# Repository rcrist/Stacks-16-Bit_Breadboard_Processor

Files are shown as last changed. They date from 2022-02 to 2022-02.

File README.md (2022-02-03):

# Stacks-16-Bit_Breadboard_Processor

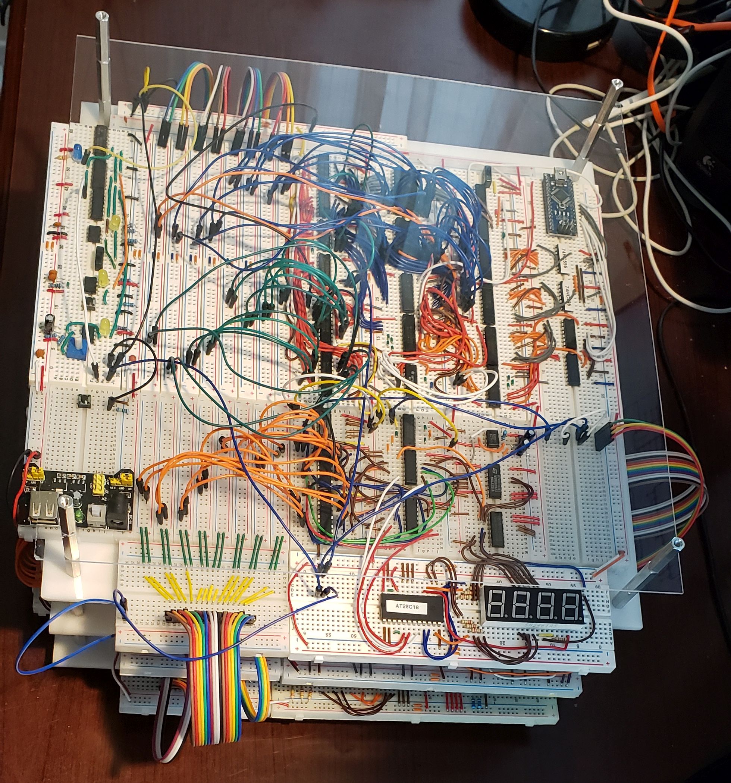
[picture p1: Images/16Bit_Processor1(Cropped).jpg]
Processor Image

Files associated with the Stacks 16-Bit Breadboard Processor project.
A full description of the project can be found on instructables at https://www.instructables.com/Stacks-A16-Bit-Breadboard-Processor/.

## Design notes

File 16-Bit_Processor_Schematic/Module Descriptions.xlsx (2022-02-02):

Layer | Module | Addr | Input | Output | Description
Top Layer | Power Supply |  | 6-12VDC | 5VDC | Computer main power supply
 | Clock |  | none | Clock | Computer main clock
 | Program Counter |  | Clock | Prog count | Computer main program counter
 | Program Memory
 | PROG | PC USB Arduino | PC USB Arduino | Prog Mem | In PROG mode, load program memory RAM with user program
 | RUN-memwr | ImmRegister | Data Bus
 | RUN-memrd | ImmRegister |  | Data Bus
 | Output Display |  | Data Bus | 7-Seg Display | Display data bus in hex
 | Branch |  | Flags | Jmp Cmd | Checks for branch cmd, if cmd, sends jmp cmd to PC
 | Branch Register |  | Inst Bus | PC | Branch register stores branch/jmp address, sends to PC load inputs
 | Decoder |  | Inst Bus | Cmd bus | Computer controller
Middle Layer | rs0 |  | Data Bus | ALU-A | Register to store ALU-A input for single cycle commands
 | rs1 |  | Data Bus | ALU-B | Register to store ALU-B input for single cycle commands
 | rd |  | ALU-Y | Data Bus | Register to store the ALU-Y result for single cycle commands
 | ALU - Math Unit |  | A & B | Y | Performs ALU addition, subtraction, AND, OR, XOR
 | ALU - Shift Unit |  | A | Y | Performs shift left, shift right, rotate left, rotate right
 | ALU - Comparator |  | A | Zero | Sets Zero output to 1 if A=0
 | Flags Register |  | Flags | Flags | 8-bit storage register for flags
Bottom Layer | rs2 |  | Data Bus | Data Bus | General purpose register for temporary 16-bit data storage
 | rs3 |  | Data Bus | Data Bus | General purpose register for temporary 16-bit data storage
 | Imm Register |  | Inst Bus | Data Bus | Storage for 16-bit data during Imm commands
 | RAM |  | Data Bus | Data Bus | HM6116 (2Kx16) RAM
 | EEPROM Programmer |  | PC USB | EEPROM | EEPROM programmer on separate power supply.

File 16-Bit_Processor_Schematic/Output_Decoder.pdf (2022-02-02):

1010 A
1011 B
1100 C
1101 D
1110 E

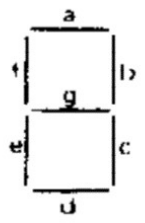
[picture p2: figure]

Assume a is lsb, g is msb | 1111 | F
Bank 3 | Bank 2 | Bank 1 | Bank 0 | I/O6 | I/O5 | I/O4 | I/O3 | I/O2 | I/O1 | I/O0
a4-a5 | a4-a5 | a4-a5 | a4-a5 | a0-a3 | g | f | e | d | c | b | a | ROM Code | Bank 0 Addr Bank 1 Addr Bank 2 Addr Bank 3 Addr
11 | 10 | 01 | 00 | 0 | 0 | 1 | 1 | 1 | 1 | 1 | 1 | 0x3F | 0x00 | 0x10 | 0x20 | 0x30
11 | 10 | 01 | 00 | 1 | 0 | 0 | 0 | 0 | 1 | 1 | 0 | 0x06 | 0x01 | 0x11 | 0x21 | 0x31
11 | 10 | 01 | 00 | 2 | 1 | 0 | 1 | 1 | 0 | 1 | 1 | 0x5B | 0x02 | 0x12 | 0x22 | 0x32
11 | 10 | 01 | 00 | 3 | 1 | 0 | 0 | 1 | 1 | 1 | 1 | 0x4F | 0x03 | 0x13 | 0x23 | 0x33
11 | 10 | 01 | 00 | 4 | 1 | 1 | 0 | 0 | 1 | 1 | 0 | 0x66 | 0x04 | 0x14 | 0x24 | 0x34
11 | 10 | 01 | 00 | 5 | 1 | 1 | 0 | 1 | 1 | 0 | 1 | 0x6D | 0x05 | 0x15 | 0x25 | 0x35
11 | 10 | 01 | 00 | 6 | 1 | 1 | 1 | 1 | 1 | 0 | 1 | 0x7D | 0x06 | 0x16 | 0x26 | 0x36
11 | 10 | 01 | 00 | 7 | 0 | 0 | 0 | 0 | 1 | 1 | 1 | 0x07 | 0x07 | 0x17 | 0x27 | 0x37
11 | 10 | 01 | 00 | 8 | 1 | 1 | 1 | 1 | 1 | 1 | 1 | 0x7F | 0x08 | 0x18 | 0x28 | 0x38
11 | 10 | 01 | 00 | 9 | 1 | 1 | 0 | 1 | 1 | 1 | 1 | 0x6F | 0x09 | 0x19 | 0x29 | 0x39
11 | 10 | 01 | 00 | a | 1 | 1 | 1 | 0 | 1 | 1 | 1 | 0x77 | 0x0A | 0x1A | 0x2A | 0x3A

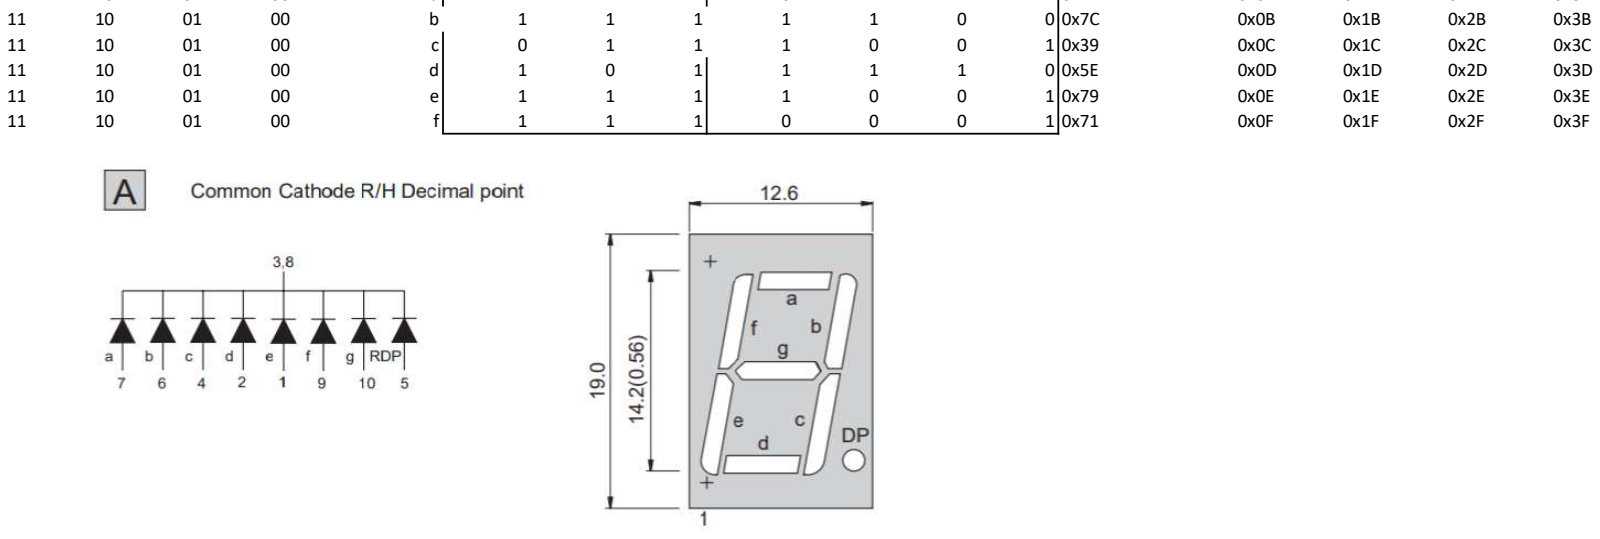
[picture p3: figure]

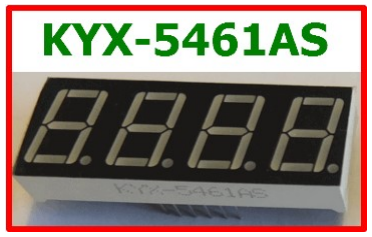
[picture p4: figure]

KYX-5461AS 4x7-Segment Display //display pins
int segA = 5; // >> 11
int segB = 13; // >> 7
int segC = 10; // >> 4

int d1 = 6; // >> 12
int d2 = 3; // >> 9
int d3 = 2; // >> 8
int d4 = 12; // >> 6

int segD = 8; // >> 2
int segE = 7; // >> 1
int segF = 4; // >> 10
int segG = 11; // >> 5
int segPt = 9; // >> 3
//display digit

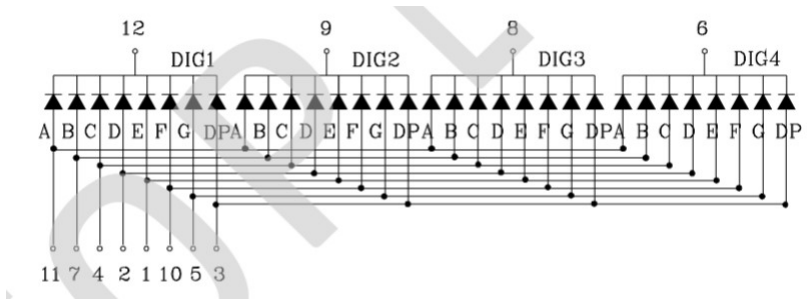
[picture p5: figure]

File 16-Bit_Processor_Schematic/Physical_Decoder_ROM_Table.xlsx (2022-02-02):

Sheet: v6
 |  |  |  | Rsrc |  |  | Rdest |  |  |  |  | ROM2 |  |  |  |  |  |  |  | ROM1 |  |  |  |  |  |  |  | ROM0 |  |  |  |  |  |  |  | ROM2 | ROM1 | ROM0
 |  |  |  | rdOE | rs2OE | rs3OE | rs3WE | rs2WE | rdWE | rs1WE | rs0WE | reserved | reserved | reserved | brWE | br2 | br1 | br0 | sf | reserved | reserved | immOE | memWE | memOE | outEN | imem | imm | aluOP5 | aluOP4 | aluOP3 | aluOP2 | aluOP1 | aluOP0 | hlt | no-op
 |  |  |  | 31 | 30 | 29 | 28 | 27 | 26 | 25 | 24 | 23 | 22 | 21 | 20 | 19 | 18 | 17 | 16 | 15 | 14 | 13 | 12 | 11 | 10 | 9 | 8 | 7 | 6 | 5 | 4 | 3 | 2 | 1 | 0
dec addr | assy mne | # Cycles | description |  |  |  |  |  |  |  |  |  |  |  |  |  |  |  |  |  |  |  |  |  |  |  |  |  |  |  |  |  |  |  |  |  |  |  | dec addr | hex addr
00 | nop | 1 | nop | 0 | 0 | 0 | 0 | 0 | 0 | 0 | 0 | 0 | 0 | 0 | 0 | 0 | 0 | 0 | 0 | 0 | 0 | 0 | 0 | 0 | 0 | 0 | 0 | 0 | 0 | 0 | 0 | 0 | 0 | 0 | 0 | 0x00 | 0x00 | 0x00 | 00 | 00
01 | hlt | 1 | hlt stop clock | 0 | 0 | 0 | 0 | 0 | 0 | 0 | 0 | 0 | 0 | 0 | 0 | 0 | 0 | 0 | 0 | 0 | 0 | 0 | 0 | 0 | 0 | 0 | 0 | 0 | 0 | 0 | 0 | 0 | 0 | 1 | 0 | 0x00 | 0x00 | 0x02 | 01 | 01
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

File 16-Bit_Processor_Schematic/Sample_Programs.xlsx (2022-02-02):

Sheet: Movi
Sample Program: Load rs0 with imm value
Load immReg with imm number |  |  | 2021-12-28 | 0x1C
Load rs0 with immReg value
Dest | rs0 | 000
 | rs1 | 001
 | rd | 010
 | immReg | 011
Source | rs0 | 000
 | rs1 | 001
 | imm | 010
 | mem | 011
 |  |  |  |  |  | Reg Signals |  |  | Decoder Signals
PM Addr | Assy | Desc | Inst (Dest) | Source | Op Code | rs0WE | rs1WE | imm | srcOE | outEN | edOE | m5 | m4 | m3 | m2 | m1 | m0 | Operation
0x0000 | movi rs0, imm | rs0 = imm | 011 | 010 | 0000 0100 | 1 |  | 1 |  |  |  |  |  |  |  |  |  | If movi, set imm=1 and rsoWE=1, next clk writes imm data to imReg
0x0001 |  |  | 000 | 000 | 0001 1100 |  |  |  |  |  |  |  |  |  |  |  |  | If imm=1, force a nop in decoder
Binary to Hex
1010 | A
1011 | B
1100 | C
1101 | D
1110 | E
1111 | F

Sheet: Add
Sample Program: Add Two Numbers
Load RS0 with 1st number |  |  | 2021-12-28 | 0x1C
Load RS1 with 2nd number |  |  | 2021-12-14 | 0x0E
Add |  |  | 42 Dec | 0x2A
Show result on output display |  |  |  | 0x002A
Dest | rs0 | 000
 | rs1 | 001
 | rd | 010
 | immReg | 011
Source | rs0 | 000
 | rs1 | 001
 | imm | 010
 | mem | 011
 |  |  |  |  |  | Reg Signals |  |  |  |  | Decoder Signals
PM Addr | Assy | Desc | Inst (Dest) | Source | Op Code | rs0WE | rs1WE | rdWE | rdOE | imm | srcOE | outEN | edOE | m5 | m4 | m3 | m2 | m1 | m0 | Operation
0x0000 | movi rs0, imm | rs0 = imm | 011 | 010 | 0000 0100 | 1 |  |  |  | 1 |  |  |  |  |  |  |  |  |  | If movi, set imm=1 and rsoWE=1, next clk writes imm data to imReg
0x0001 |  |  | 000 | 000 | 0001 1100 | 1 |  |  |  | 1 |  |  |  |  |  |  |  |  |  | If imm=1, force a nop in decoder
0x0000 | movi rs1, imm | rs1 = imm | 011 | 010 | 0000 0100 |  | 1 |  |  | 1 |  |  |  |  |  |  |  |  |  | If movi, set imm=1 and rs1WE=1, next clk writes imm data to imReg
0x0001 |  |  | 000 | 000 | 0000 1110 |  | 1 |  |  | 1 |  |  |  |  |  |  |  |  |  | If imm=1, force a nop in decoder
0x0100 | add | rd = rs0 + rs1 | 000 | 000 | 0000 1110 |  |  | 1 |  |  |  |  |  | 1 | 0 | 0 | 0 | 0 | 0
0x0101 | hex | hex disp = D |  |  | 0001 1011 |  |  |  | 1 |  |  | 1 |  |  |  |  |  |  |  | Disp = 0x28 = 42 dec
Binary to Hex
1010 | A
1011 | B
1100 | C
1101 | D
1110 | E
1111 | F

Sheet: And
Sample Program: AND Two Numbers
Load RS0 with 1st number |  |  |  | 0x5555
Load RS1 with 2nd number |  |  |  | 0x5500
And |  |  |  | 0x5500
Show result on output display |  |  |  | 0x5500
Dest | rs0 | 000
 | rs1 | 001
 | rd | 010
 | immReg | 011
Source | rs0 | 000
 | rs1 | 001
 | imm | 010
 | mem | 011
 |  |  |  |  |  | Reg Signals |  |  |  |  | Decoder Signals
PM Addr | Assy | Desc | Inst (Dest) | Source | Op Code | rs0WE | rs1WE | rdWE | rdOE | imm | srcOE | outEN | edOE | m5 | m4 | m3 | m2 | m1 | m0 | Operation
0x0000 | movi rs0, imm | rs0 = imm | 011 | 010 | 0000 0100 | 1 |  |  |  | 1 |  |  |  |  |  |  |  |  |  | If movi, set imm=1 and rsoWE=1, next clk writes imm data to imReg
0x0001 |  |  | 010 | 101 | 0101 0101 | 1 |  |  |  | 1 |  |  |  |  |  |  |  |  |  | If imm=1, force a nop in decoder
0x0000 | movi rs1, imm | rs1 = imm | 011 | 010 | 0000 0100 |  | 1 |  |  | 1 |  |  |  |  |  |  |  |  |  | If movi, set imm=1 and rs1WE=1, next clk writes imm data to imReg
0x0001 |  |  | 010 | 101 | 0000 0100 |  | 1 |  |  | 1 |  |  |  |  |  |  |  |  |  | If imm=1, force a nop in decoder
0x0100 | add | rd = rs0 + rs1 | 000 | 000 | 0000 1110 |  |  | 1 |  |  |  |  |  | 1 | 0 | 1 | 0 | 0 | 0
0x0101 | hex | hex disp = D |  |  | 0001 1011 |  |  |  | 1 |  |  | 1 |  |  |  |  |  |  |  | Disp result = 0x5500
Binary to Hex
1010 | A
1011 | B
1100 | C
1101 | D
1110 | E
1111 | F

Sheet: Mwt
Sample Program: Write Rd to mem
Load RS0 with 1st number |  |  | 2021-12-28 | 0x1C
Load RS1 with 2nd number |  |  | 2021-12-14 | 0x0E
Add |  |  | 42 Dec | 0x2A
Write rd result to mem at iem addr |  |  |  | 0x002A
Read mem and output on hex display
Dest | rs0 | 000
 | rs1 | 001
 | rd | 010
 | immReg | 011
 | mem | 100
 | out | 101
Source | rs0 | 000
 | rs1 | 001
 | rd | 010
 | imm | 011
 | mem | 100
 |  |  |  |  |  | Reg Signals |  |  |  |  |  |  |  | Decoder Signals
PM Addr | Assy | Desc | Inst (Dest) | Source | Op Code | rs0WE | rs1WE | rdWE | rdOE | memWE | memOE | mem | imm | srcOE | outEN | edOE | m5 | m4 | m3 | m2 | m1 | m0 | Operation
0x0000 | movi rs0, imm | rs0 = imm | 011 | 010 | 0000 0100 | 1 |  |  |  |  |  |  | 1 |  |  |  |  |  |  |  |  |  | If movi, set imm=1 and rsoWE=1, next clk writes imm data to imReg
0x0001 |  |  | 000 | 000 | 0001 1100 | 1 |  |  |  |  |  |  | 1 |  |  |  |  |  |  |  |  |  | If imm=1, force a nop in decoder
0x0000 | movi rs1, imm | rs1 = imm | 011 | 010 | 0000 0100 |  | 1 |  |  |  |  |  | 1 |  |  |  |  |  |  |  |  |  | If movi, set imm=1 and rs1WE=1, next clk writes imm data to imReg
0x0001 |  |  | 000 | 000 | 0000 1110 |  | 1 |  |  |  |  |  | 1 |  |  |  |  |  |  |  |  |  | If imm=1, force a nop in decoder
0x0100 | add | rd = rs0 + rs1 | 000 | 000 | 0000 1110 |  |  | 1 |  |  |  |  |  |  |  |  | 1 | 0 | 0 | 0 | 0 | 0
0x0101 | mrt iem, rd | mem[iem] = rd | 100 | 010 | 0001 1011 |  |  |  | 1 | 1 |  | 1 |  |  |  |  |  |  |  |  |  |  | Disp = 0x28 = 42 dec
0x0110 | mrd out, iem | out = mem[iem] | 101 | 100 | 0001 1011 |  |  |  |  |  | 1 | 1 |  |  | 1
Binary to Hex
1010 | A
1011 | B
1100 | C
1101 | D
1110 | E
1111 | F

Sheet: Sf
Sample Program: Store flags with Zero=1
Leave rs0 at a value of 0x000 |  |  | 2021-12-28 | 0x1C
Perform ALU comparison with 0x0000
Store flags in flag register
Verify that Zero flag is set
Dest | rs0 | 001 | rs0WE
 | rs1 | 010 | rs1WE
 | rd | 011 | rdWE
Source | rd | 001 | rdOE
 |  |  |  |  |  | Dest Signals |  |  | Src Signals | Decoder Signals
PM Addr | Assy | Desc | Inst (Dest) | Source | Op Code | rs0WE | rs1WE | rdWE | rdOE | sf | br | imm | iem | memWE | outWE | memOE | m5 | m4 | m3 | m2 | m1 | m0 | Operation
0x0000 | sf | flgReg = flags |  |  |  |  |  |  |  | 1 |  |  |  |  |  |  |  |  |  |  |  |  | Store ALU flags in flag register
Binary to Hex
1010 | A
1011 | B
1100 | C
1101 | D
1110 | E
1111 | F

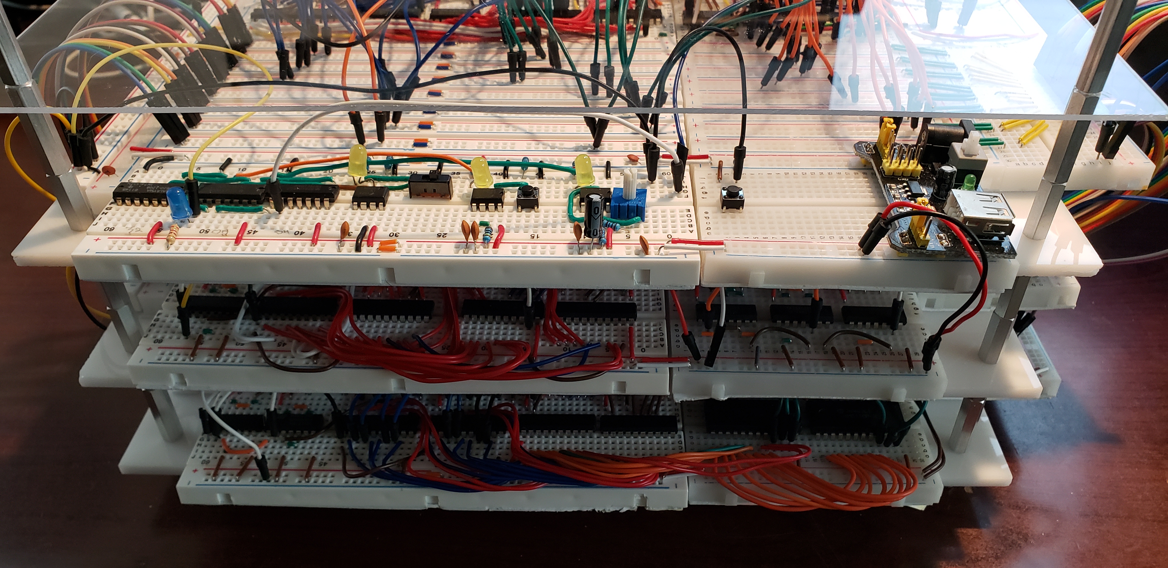
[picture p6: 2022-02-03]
Images/16Bit_Processor2.jpg

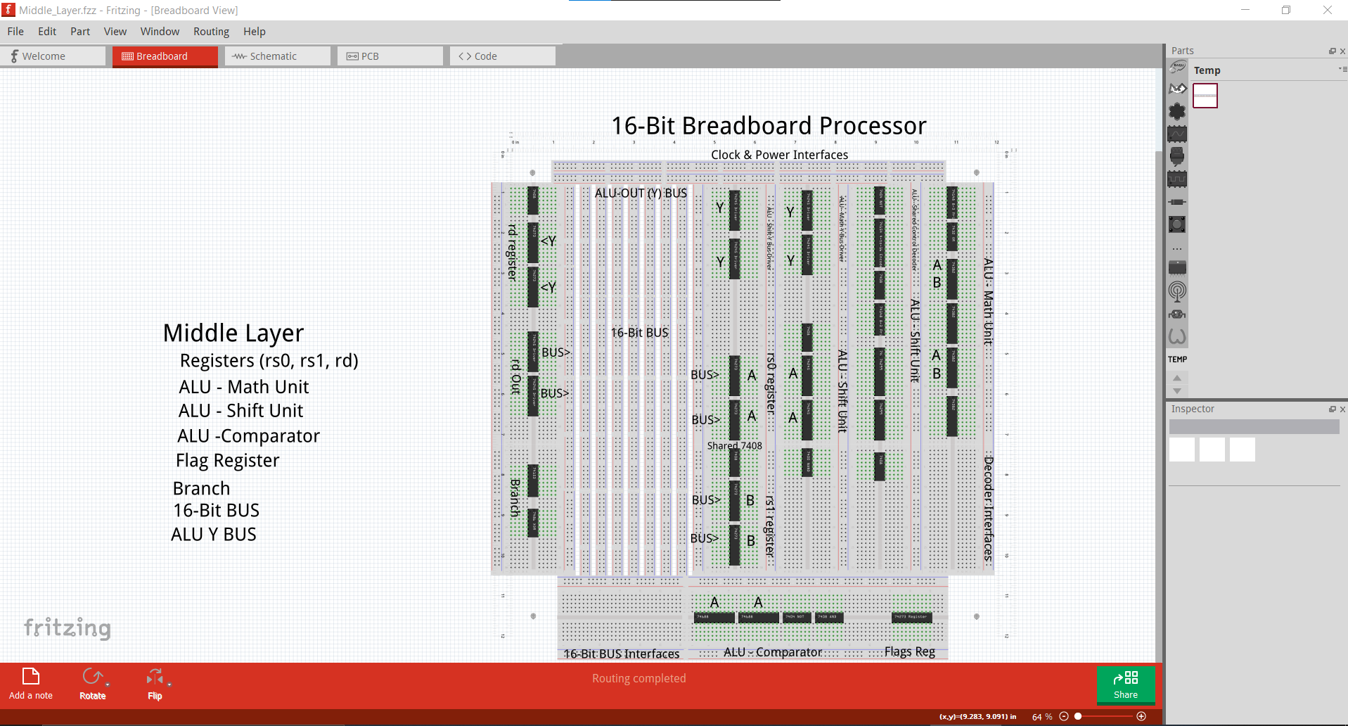
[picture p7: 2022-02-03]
Images/Middle_Layer.png

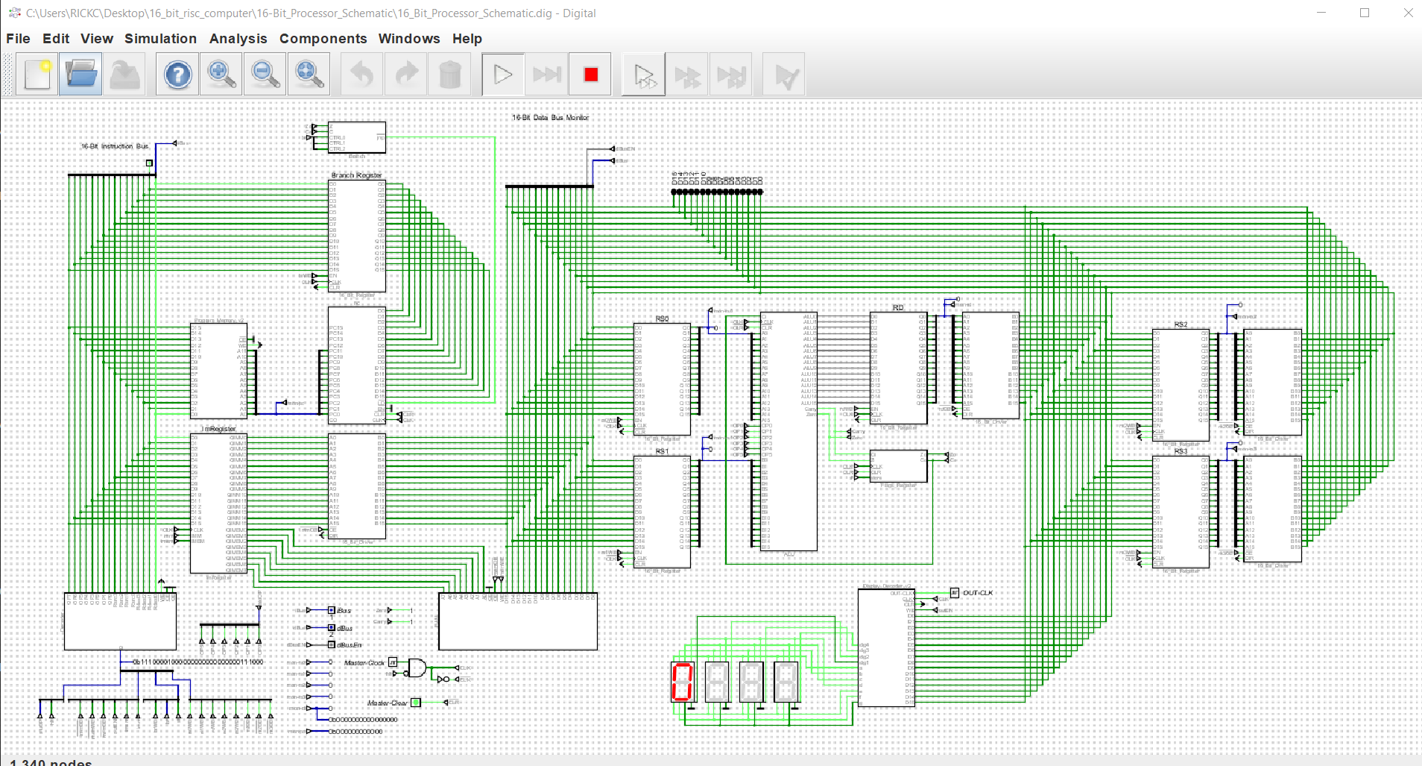
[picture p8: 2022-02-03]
Images/Physical_Simulation.png

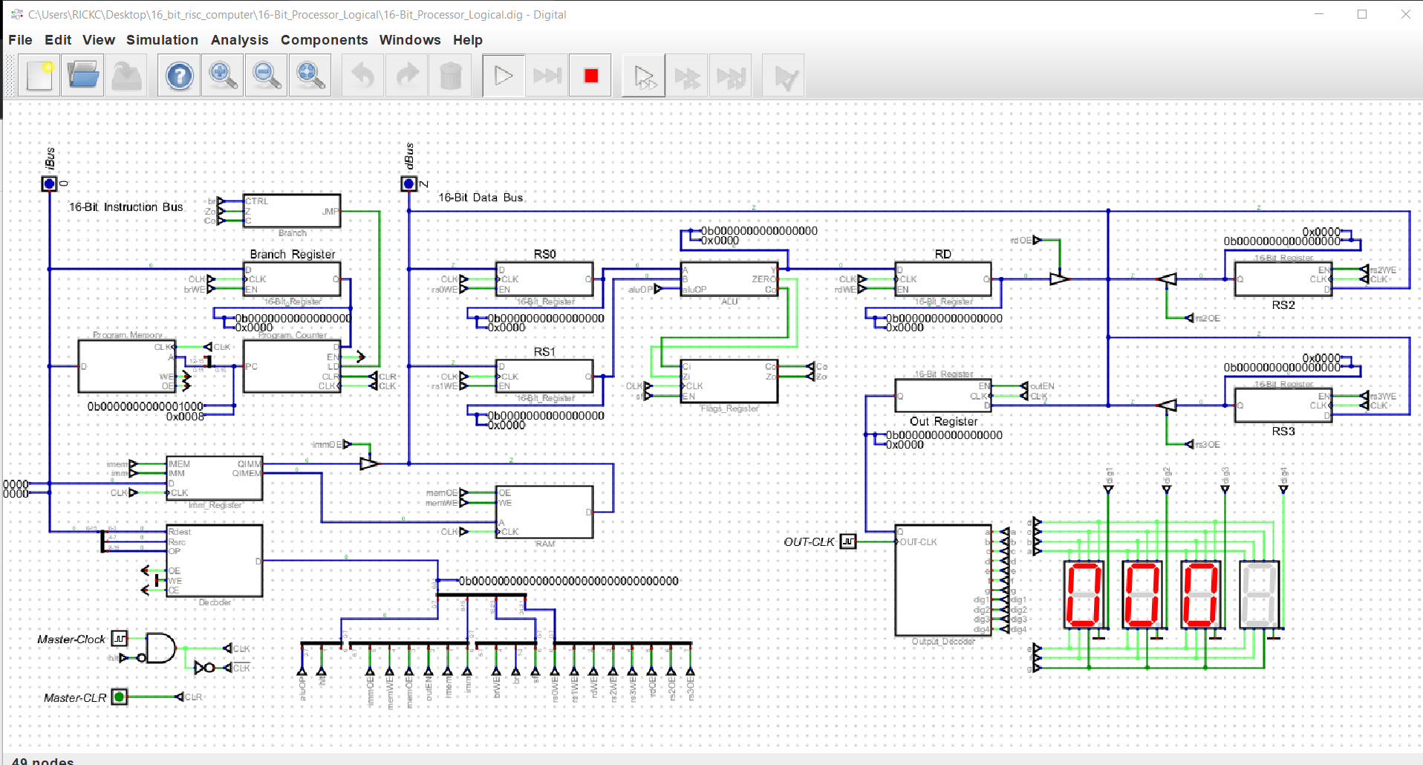
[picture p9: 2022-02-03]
Images/Logical_Simulation.png

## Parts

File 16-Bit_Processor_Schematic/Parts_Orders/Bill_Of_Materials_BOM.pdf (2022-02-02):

Subsystem | Part # | Qty | Desc | Supplier | Notes
Enclosure | 7328 White | 3 | 12" x 12" x 3/6" White Acrylic Sheet | Etsy - Delvies Plastics
Enclosure | | 1 | 12" x 12" x 1/16" Clear Plexiglass Acrylic Sheet | Etsy - Delvies Plastics
Enclosure | | 1 | Standoff Kit 6-32 Assorted | Amazon
Enclosure | Deyue | 18 | Breadboard - Full Size 830 tie points | Amazon - Deyue | Use power strip on one side for buses
Enclosure | PateLie | 18 | Breadboard - Half Size 400 tie points | Amazon - PateLie Store | Use power strip on one side for buses
Wire | BOJACK 14 Vaules 840 pcs | 4 | Pre-cut Jumper Wires | Amazon
Wire | ACEIRMC 4set 65pcs | 2 | Male-to-Male Jumper Wires | Amazon
Wire | | 6 | 40-pin Jumper Ribbon Cables - 6", 8", 10" | Amazon
Resistor | 220 ohm | 100 | 220 ohm | Jameco
Resistor | 330 ohm | 100 | 330 ohm | Jameco
Capacitor | 0.01 uF | 10 | 0.01 uF Electrolytic | Jameco
Capacitor | 0.01 uF | 100 | 0.01 uf Ceramic bypass cap | Jameco
Power Supply | HitLetgo 5pc 3.3V 5V | 5 | Breadboard Power Supply | Amazon
Register - RS0 | SN74HC273N | 2 | 8-Bit register | Mouser
Register - RS0 | SN74AHCT08N | 1 | Quad 2-input AND | Mouser
Register - RS1 | SN74HC273N | 2 | 8-Bit register | Mouser
Register - RS1 | SN74AHCT08N | 1 | Quad 2-input AND | Mouser
Register - Rd | SN74HC273N | 2 | 8-Bit register | Mouser
Register - Rd | SN74AHCT08N | 1 | Quad 2-input AND | Mouser
Register - RS2 | SN74HC273N | 2 | 8-Bit register | Mouser
Register - RS2 | SN74AHCT08N | 1 | Quad 2-input AND | Mouser
Register - RS3 | SN74HC273N | 2 | 8-Bit register | Mouser
Register - RS3 | SN74AHCT08N | 1 | Quad 2-input AND | Mouser
Driver - Rd | SN74HC245N | 2 | 8-Bit Bidirectional Line Driver | Mouser
Driver - RS2 | SN74HC245N | 2 | 8-Bit Bidirectional Line Driver | Mouser
Driver - RS3 | SN74HC245N | 2 | 8-Bit Bidirectional Line Driver | Mouser
Register - Flags | SN74HC273N | 1 | 8-Bit register | Mouser
Register - Flags | SN74AHCT08N | 1 | Quad 2-input AND | Mouser
Output Module | SN74HC273N | 2 | 8-Bit register | Mouser
Output Module | SN74AHCT08N | 1 | Quad 2-input AND | Mouser
Output Module | SN74HC253N | 2 | Dual 4-line to 1-line data | Mouser
Output Module | SN74HC161N | 1 | Hex synch. counter | Jameco
Output Module | SN74LS139 | 1 | Dual 2-to-4 line decoder | Jameco
Output Module | AT28C16 | 1 | 16K (2Kx8) EEPROM | Jameco
Output Module | CC-5461AS | 1 | Toplight 4-Digit 7-Segment Display | Jameco
ALU | SN74AHCT04N | 3 | Hex inverter | Mouser
ALU | SN74HC154N | 1 | 4-line to 16-line Decoder | Jameco
ALU | SN74AHCT08N | 4 | Quad 2-input AND | Mouser
ALU | SN74HC148N | 2 | 8-line to 3-line priority encoder | Mouser
ALU | SN74HC245N | 6 | 8-Bit Bidirectional Line Driver | Mouser
ALU | SN74HC299N | 2 | 8-Bit Shift Register | Mouser
ALU | SN74AHCT32N | 1 | Quad 2-input OR | Mouser
ALU | MC74F382N | 4 | 4-Bit ALU | Amazon
ALU | SN74HC688N | 2 | 8-bit Identity Comparator | Mouser
Branch Module | SN74LS153 | 1 | Dual 4-line to 1-line data | Mouser
Branch Module | SN74AHCT86N | 1 | Quad 2-input XOR | Mouser
Branch Module | SN74AHCT04N | 1 | Hex inverter | Mouser
Branch Register | SN74HC273N | 2 | 8-Bit register | Mouser
Branch Register | SN74AHCT08N | 1 | Quad 2-input AND | Mouser
Program Counter | SN74HC161N | 4 | Hex synch. counter | Jameco
Program Memory | Arduino NANO | 1 | Arduino NANO | Amazon
Program Memory | SN74AHCT04N | 1 | Hex inverter | Mouser
Program Memory | SN74AHCT08N | 1 | Quad 2-input AND | Mouser
Program Memory | SN74HC595N | 4 | 8-bit shift registers, Serial-In, Parallel-Out | Mouser
Program Memory | SN74HC245N | 6 | 8-Bit Bidirectional Line Driver | Mouser
Program Memory | SN74LS157 | 1 | quad 2-line to 1-line data selector | Mouser
Program Memory | HM6116 | 2 | 2Kx8 RAM | Jameco
IM Register | SN74HC273N | 2 | 8-Bit register | Mouser
IM Register | SN74AHCT08N | 1 | Quad 2-input AND | Mouser
IM Register | SN74AHCT32N | 1 | Quad 2-input OR | Mouser
Driver - IM | SN74HC245N | 2 | 8-Bit Bidirectional Line Driver | Mouser
RAM | HM6116 | 2 | 2Kx8 RAM | Jameco
Decoder | SN74AHCT32N | 1 | Quad 2-input OR | Mouser
Decoder | SN74HC244N | 2 | Octal buffer | Mouser
Decoder | AT28C256 | 3 | 256K (32Kx8) EEPROM | Jameco
Decoder | SN74LS138 | 2 | 3-to-8 line decoder | Mouser
Decoder | SN74AHCT04N | 2 | Hex inverter | Mouser
Clock Module | NE555 | 3 | Timer | Mouser
Clock Module | SN74AHCT04N | 1 | Hex inverter | Mouser
Clock Module | SN74AHCT08N | 1 | Quad 2-input AND | Mouser
Clock Module | SN74AHCT32N | 1 | Quad 2-input OR | Mouser

Clock Module | 1M Variable Resistor | 1 | 1M ohm variable resistor | Jameco
Clock Module | Mom. Switch | 1 | Breadboard momentary switch | Jameco
Clock Module | Slide Switch | 1 | SPDT breadboard slide switch | Jameco
Clock Module | LED | 2 | Yellow | Jameco
Clock Module | LED | 1 | Blue | Jameco

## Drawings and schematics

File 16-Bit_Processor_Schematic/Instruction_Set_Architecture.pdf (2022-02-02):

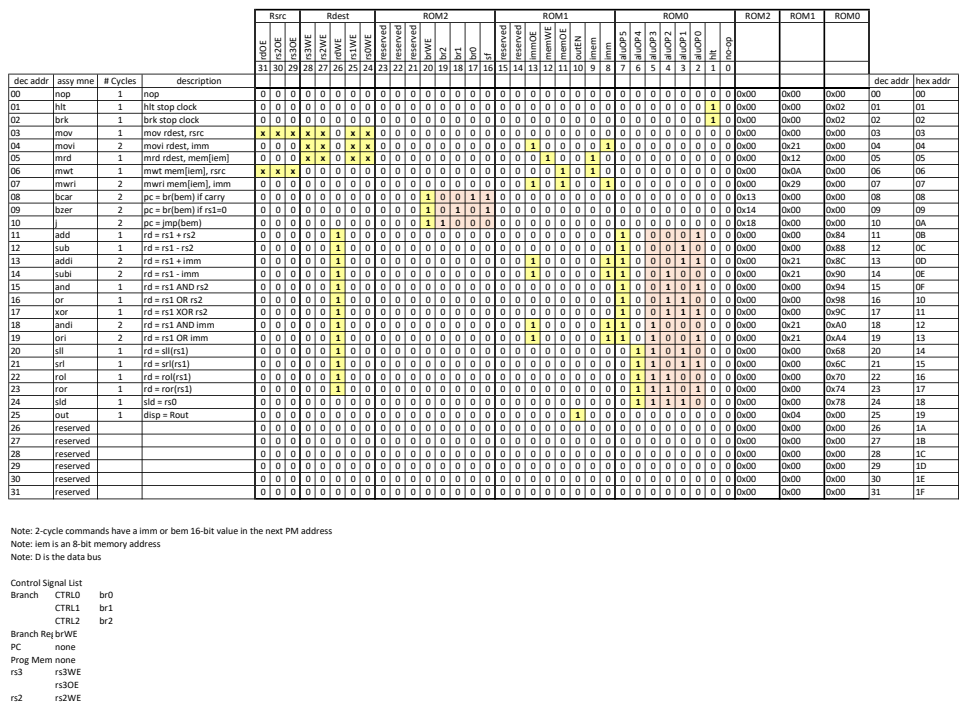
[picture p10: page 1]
nop; hlt; hlt stop clock; brk; brk stop clock; mov; mov rdest, rsrc; movi; movi rdest, imm; mrd; mrd rdest, mem[iem]; mwt; mwt mem[iem], rsrc; mwri; mwri mem[iem], imm; bcar; pc = br(bem) if carry; bzer; pc = br(bem) if rs1=0; pc = jmp(bem); add; sub; addi; rd = rs1 + imm; subi; rd = rs1 - imm; and; rd = rs1 AND rs2; xor; rd = rs1 XOR rs2; andi; rd = rs1 AND imm; ori; rd = rs1 OR imm; sll; rd = sll(rs1); srl; rd = srl(rs1); rol; rd = rol(rs1); ror; rd = ror(rs1); sld; sld = rs0; out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

rs2OE | rs3OE | rs3WE | rs2WE | rdWE | rs1WE | rs0WE | reserved | reserved | reserved | brWE | br2 | br1 | br0 | sf | reserved | reserved | immOE | memWE | memOE | outEN | imem | imm | aluOP5 | aluOP4 | aluOP3 | aluOP2 | aluOP1 | aluOP0 | hlt | no⁻op | ROM2 | ROM1 | ROM0 rdOE

Rsrc | Rdest | ROM2 | ROM1 | ROM0

dec addr | assy mne | # Cycles | description | | | | | | | | | | | | | | | | | | | | | | | | | | | | | | | | dec addr | hex addr

Note: 2-cycle commands have a imm or bem 16-bit value in the next PM address
Note: iem is an 8-bit memory address
Note: D is the data bus

Control Signal List

Branch RegbrWE
Prog Mem none

rs2OE
Decoder none
Imm Reg imm
imem
immOE
RAM | memWE
| memOE
Out Reg outEN
rs1 | rs1WE
rs0 | rs0WE
ALU | aluop0
| aluop1
| aluop2
| aluop3
| aluop4
| aluop5
Flag Reg sf
rd | rdWE
| rdOE
